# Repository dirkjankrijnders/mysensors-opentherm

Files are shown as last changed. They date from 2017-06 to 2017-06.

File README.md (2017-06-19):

# mysensors-opentherm
Mysensors opentherm gateway

Effectively a open of http://otgw.tclcode.com, but with external power brick and a MYSX-2.0 connector instead of the RS-232 interface. The PCB is designed to fit in [this](http://www.ebay.com/itm/221899779029) enclosure and connect to https://github.com/dirkjankrijnders/MYS-PMS7003.

3D render of the PCB:

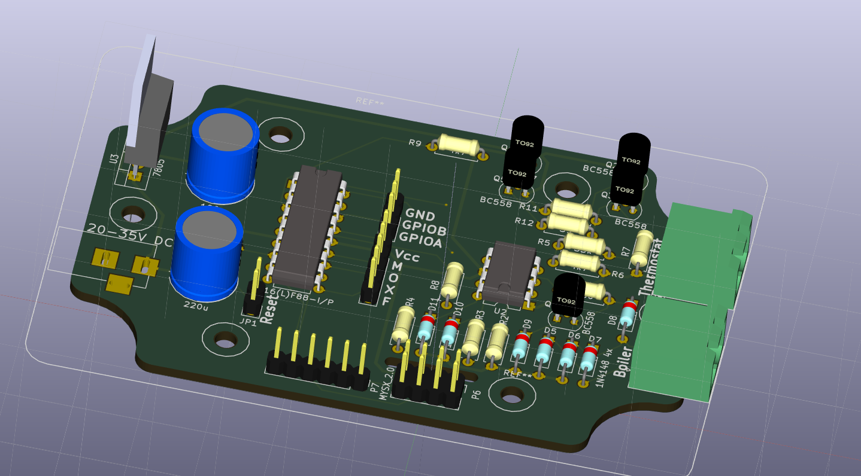
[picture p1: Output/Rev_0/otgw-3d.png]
3D render


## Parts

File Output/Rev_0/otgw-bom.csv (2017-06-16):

Reference | Value | Footprint | Datasheet
P4 | CONN_01X02 | Connectors_Phoenix:PhoenixContact_MSTBA-G_02x5.00mm_Angled
P5 | CONN_01X02 | Connectors_Phoenix:PhoenixContact_MSTBA-G_02x5.00mm_Angled
C1 | 220u | Capacitors_THT:CP_Radial_D10.0mm_P5.00mm_P7.50mm
U3 | 7805 | TO_SOT_Packages_THT:TO-220_Vertical
C2 | 100u | Capacitors_THT:CP_Radial_D10.0mm_P5.00mm_P7.50mm
U1 | PIC16(L)F88-I/P | Housings_DIP:DIP-18_W7.62mm
R10 | 15k | Resistors_THT:R_Axial_DIN0207_L6.3mm_D2.5mm_P7.62mm_Horizontal
JP1 | Jumper | Pin_Headers:Pin_Header_Angled_1x02_Pitch2.54mm
P3 | CONN_01X03 | Pin_Headers:Pin_Header_Straight_1x03_Pitch2.54mm
P2 | CONN_01X05 | Pin_Headers:Pin_Header_Straight_1x05_Pitch2.54mm
D5 | 1N4148 | Diodes_THT:D_DO-35_SOD27_P7.62mm_Horizontal
D6 | 1N4148 | Diodes_THT:D_DO-35_SOD27_P7.62mm_Horizontal
D7 | 1N4148 | Diodes_THT:D_DO-35_SOD27_P7.62mm_Horizontal
D8 | 1N4148 | Diodes_THT:D_DO-35_SOD27_P7.62mm_Horizontal
D9 | 4V7 | Diodes_THT:D_DO-35_SOD27_P7.62mm_Horizontal
Q1 | BC558 | TO_SOT_Packages_THT:TO-92_Molded_Narrow
R1 | 330 | Resistors_THT:R_Axial_DIN0207_L6.3mm_D2.5mm_P7.62mm_Horizontal
R3 | 220 | Resistors_THT:R_Axial_DIN0207_L6.3mm_D2.5mm_P7.62mm_Horizontal
R2 | 100 | Resistors_THT:R_Axial_DIN0207_L6.3mm_D2.5mm_P7.62mm_Horizontal
D10 | 15V | Diodes_THT:D_DO-35_SOD27_P7.62mm_Horizontal
D11 | 4V3 | Diodes_THT:D_DO-35_SOD27_P7.62mm_Horizontal
U2 | PC827 | Housings_DIP:DIP-8_W7.62mm
R8 | 1k5 | Resistors_THT:R_Axial_DIN0207_L6.3mm_D2.5mm_P7.62mm_Horizontal
R4 | 330 | Resistors_THT:R_Axial_DIN0207_L6.3mm_D2.5mm_P7.62mm_Horizontal
Q3 | BC558 | TO_SOT_Packages_THT:TO-92_Molded_Narrow
Q2 | BC558 | TO_SOT_Packages_THT:TO-92_Molded_Narrow
R7 | 33k | Resistors_THT:R_Axial_DIN0207_L6.3mm_D2.5mm_P7.62mm_Horizontal
R5 | 33k | Resistors_THT:R_Axial_DIN0207_L6.3mm_D2.5mm_P7.62mm_Horizontal
R6 | 4k7 | Resistors_THT:R_Axial_DIN0207_L6.3mm_D2.5mm_P7.62mm_Horizontal
R11 | 100 | Resistors_THT:R_Axial_DIN0207_L6.3mm_D2.5mm_P7.62mm_Horizontal
R12 | 39 | Resistors_THT:R_Axial_DIN0207_L6.3mm_D2.5mm_P7.62mm_Horizontal
Q5 | BC558 | TO_SOT_Packages_THT:TO-92_Molded_Narrow
Q4 | BC547 | TO_SOT_Packages_THT:TO-92_Molded_Narrow
R9 | 4k7 | Resistors_THT:R_Axial_DIN0207_L6.3mm_D2.5mm_P7.62mm_Horizontal
P7 | CONN_01X06 | Pin_Headers:Pin_Header_Straight_1x06_Pitch2.54mm
P6 | MYSX_2.0 | mysensors_connectors:MYSX_2.0
CON1 | BARREL_JACK | Connectors:BARREL_JACK

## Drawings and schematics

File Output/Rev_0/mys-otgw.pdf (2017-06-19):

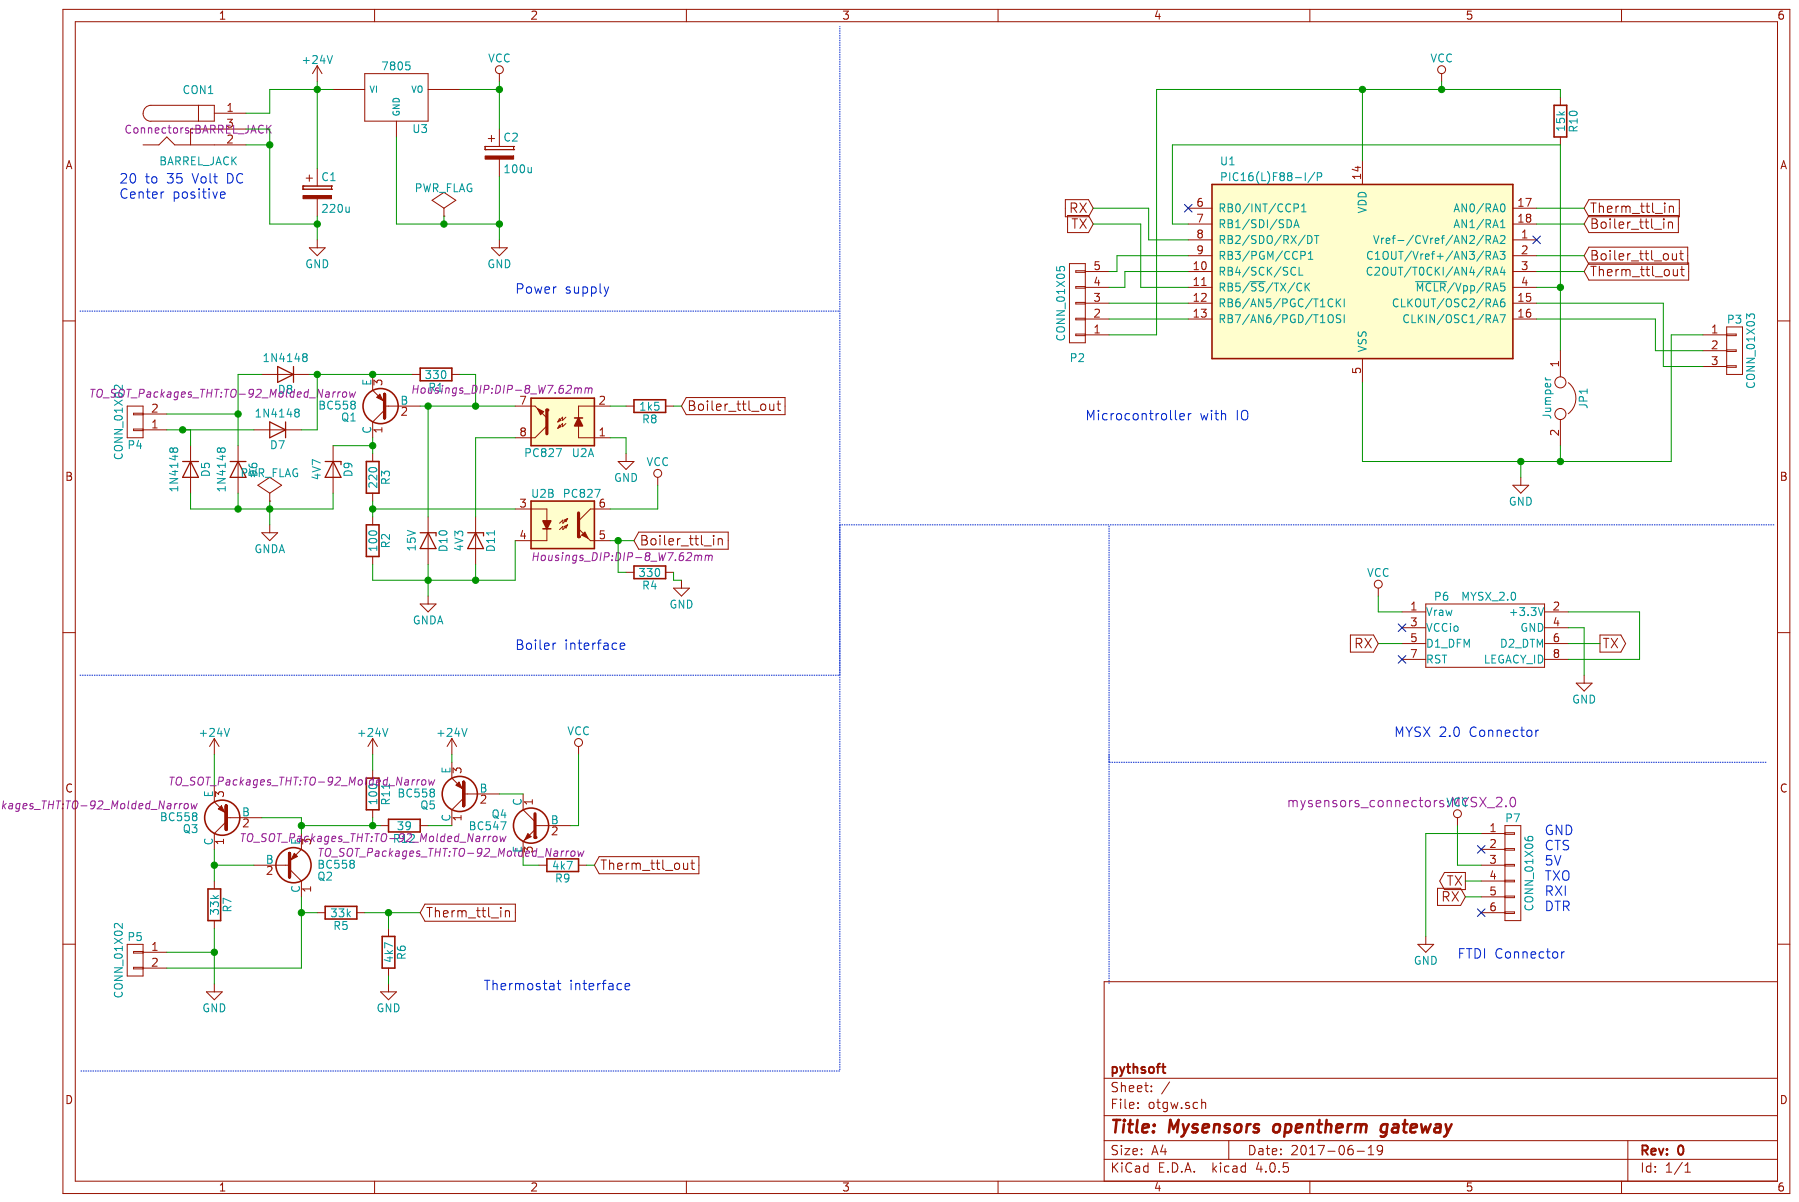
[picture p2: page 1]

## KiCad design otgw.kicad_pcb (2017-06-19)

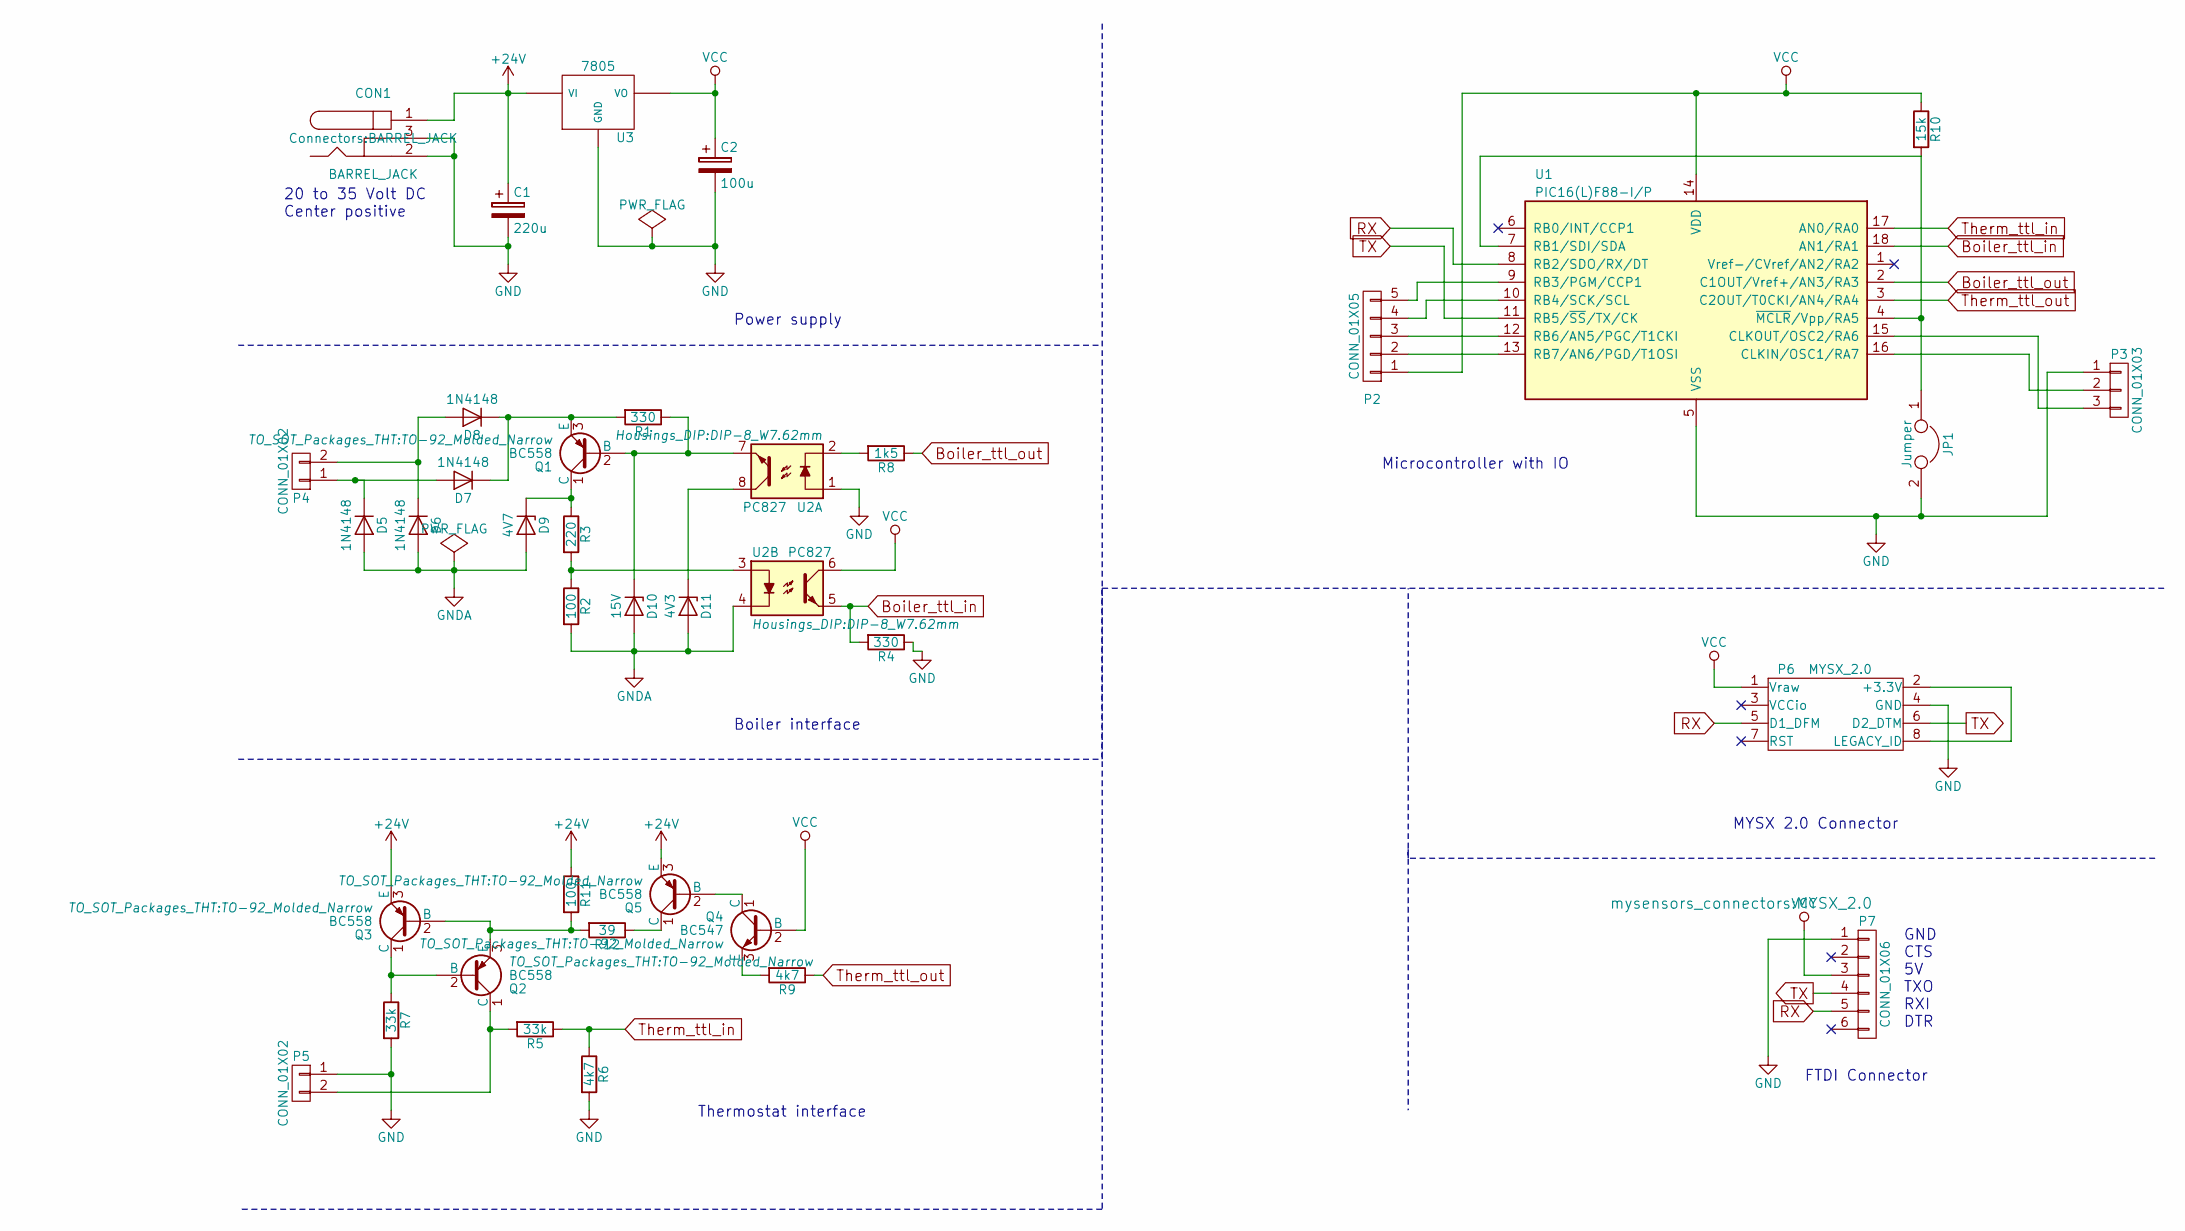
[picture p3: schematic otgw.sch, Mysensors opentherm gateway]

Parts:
C1: 220u; CP_Radial_D10.0mm_P5.00mm_P7.50mm
C2: 100u; CP_Radial_D10.0mm_P5.00mm_P7.50mm
CON1: BARREL_JACK
D5, D6, D7, D8: 1N4148; D_DO-35_SOD27_P7.62mm_Horizontal
D9: 4V7; D_DO-35_SOD27_P7.62mm_Horizontal
D10: 15V; D_DO-35_SOD27_P7.62mm_Horizontal
D11: 4V3; D_DO-35_SOD27_P7.62mm_Horizontal
JP1: Jumper; Pin_Header_Angled_1x02_Pitch2.54mm
P2: CONN_01X05; Pin_Header_Straight_1x05_Pitch2.54mm
P3: CONN_01X03; Pin_Header_Straight_1x03_Pitch2.54mm
P4, P5: CONN_01X02; PhoenixContact_MSTBA-G_02x5.00mm_Angled
P6: MYSX_2.0
P7: CONN_01X06; Pin_Header_Straight_1x06_Pitch2.54mm
Q1, Q2, Q3, Q5: BC558; TO-92_Molded_Narrow
Q4: BC547; TO-92_Molded_Narrow
R1, R4: 330; R_Axial_DIN0207_L6.3mm_D2.5mm_P7.62mm_Horizontal
R2, R11: 100; R_Axial_DIN0207_L6.3mm_D2.5mm_P7.62mm_Horizontal
R3: 220; R_Axial_DIN0207_L6.3mm_D2.5mm_P7.62mm_Horizontal
R5, R7: 33k; R_Axial_DIN0207_L6.3mm_D2.5mm_P7.62mm_Horizontal
R6, R9: 4k7; R_Axial_DIN0207_L6.3mm_D2.5mm_P7.62mm_Horizontal
R8: 1k5; R_Axial_DIN0207_L6.3mm_D2.5mm_P7.62mm_Horizontal
R10: 15k; R_Axial_DIN0207_L6.3mm_D2.5mm_P7.62mm_Horizontal
R12: 39; R_Axial_DIN0207_L6.3mm_D2.5mm_P7.62mm_Horizontal
U1: PIC16(L)F88-I/P; DIP-18_W7.62mm
U2: PC827; DIP-8_W7.62mm
U3: 7805; TO-220_Vertical

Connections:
+24V: C1.1, CON1.1, Q3.3 (E), Q5.3 (E), R11.1, U3.1 (VI)
Boiler_ttl_in: R4.2, U1.18 (AN1/RA1), U2.5
Boiler_ttl_out: R8.1, U1.2 (C1OUT/Vref+/AN3/RA3)
GND: C1.2, C2.2, CON1.2, CON1.3, JP1.2, P3.1, P5.1, P6.4 (GND), P7.1, R4.1, R6.2, R7.2, U1.5 (VSS), U2.1, U3.2 (GND)
GNDA: D5.2 (A), D6.2 (A), D9.2 (A), D10.2 (A), D11.2 (A), R2.2, U2.4
unnamed: D5.1 (K), D7.2 (A), P4.1
unnamed: D6.1 (K), D8.2 (A), P4.2
unnamed: D7.1 (K), D8.1 (K), Q1.3 (E), R1.2
unnamed: D9.1 (K), Q1.1 (C), R3.1
unnamed: D10.1 (K), Q1.2 (B), R1.1, U2.7
unnamed: D11.1 (K), U2.8
unnamed: JP1.1, R10.2, U1.4 (~MCLR~/Vpp/RA5), U1.7 (RB1/SDI/SDA)
unnamed: P2.2, U1.13 (RB7/AN6/PGD/T1OSI)
unnamed: P2.3, U1.12 (RB6/AN5/PGC/T1CKI)
unnamed: P2.4, U1.10 (RB4/SCK/SCL)
unnamed: P2.5, U1.9 (RB3/PGM/CCP1)
unnamed: P3.2, U1.16 (CLKIN/OSC1/RA7)
unnamed: P3.3, U1.15 (CLKOUT/OSC2/RA6)
unnamed: P5.2, Q2.1 (C), R5.2
unnamed: P6.2 (+3.3V), P6.8 (LEGACY_ID)
unnamed: Q2.2 (B), Q3.1 (C), R7.1
unnamed: Q2.3 (E), Q3.2 (B), R11.2, R12.2
unnamed: Q4.1 (C), Q5.2 (B)
unnamed: Q4.3 (E), R9.2
unnamed: Q5.1 (C), R12.1
unnamed: R2.1, R3.2, U2.3
unnamed: R8.2, U2.2
RX: P6.5 (D1_DFM), P7.5, U1.8 (RB2/SDO/RX/DT)
TX: P6.6 (D2_DTM), P7.4, U1.11 (RB5/~SS~/TX/CK)
Therm_ttl_in: R5.1, R6.1, U1.17 (AN0/RA0)
Therm_ttl_out: R9.1, U1.3 (C2OUT/T0CKI/AN4/RA4)
VCC: C2.1, P2.1, P6.1 (Vraw), P7.3, Q4.2 (B), R10.1, U1.14 (VDD), U2.6, U3.3 (VO)

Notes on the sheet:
GND CTS 5V TXO RXI DTR
MYSX 2.0 Connector
FTDI Connector
Thermostat interface
Boiler interface
Power supply
20 to 35 Volt DC Center positive
Microcontroller with IO

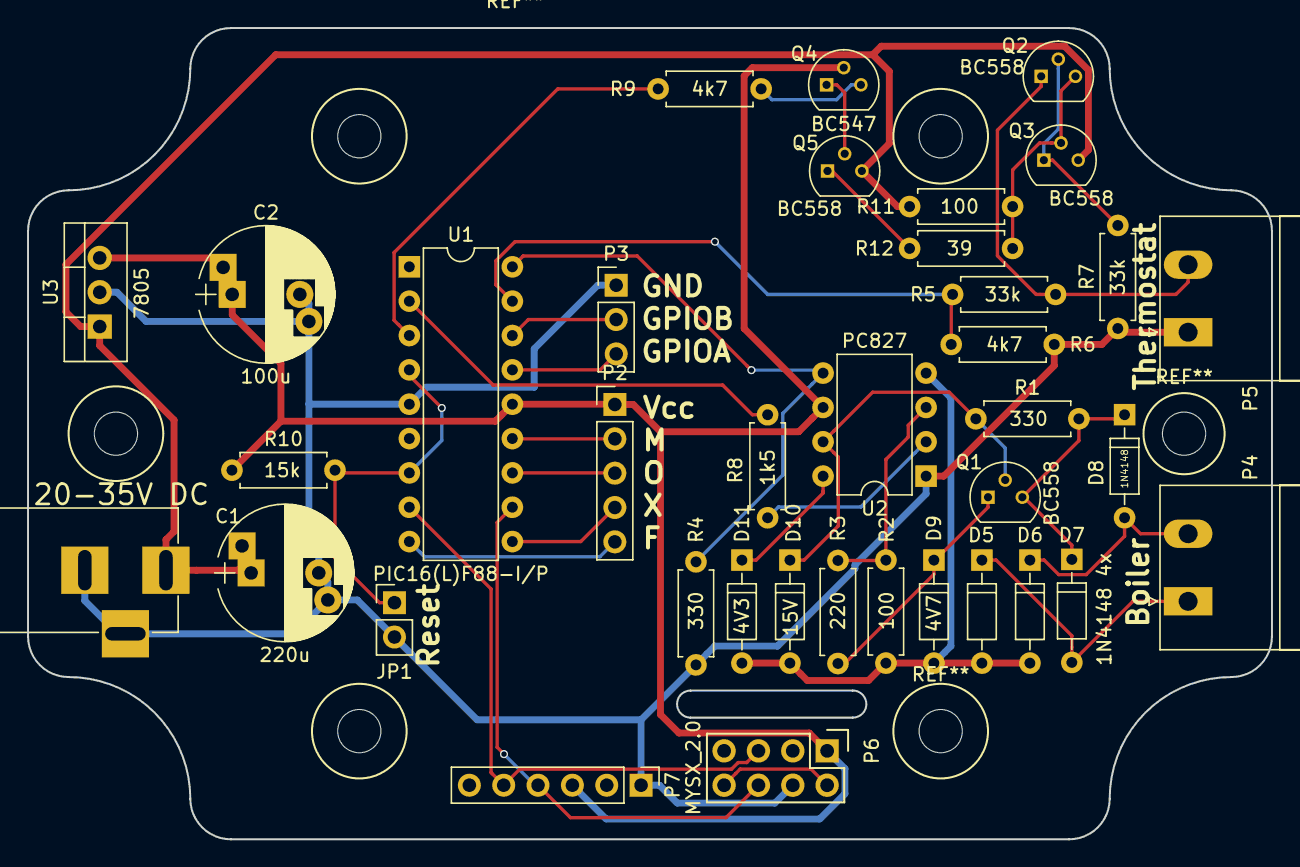
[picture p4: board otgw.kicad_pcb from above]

Board: 2 copper layers, 92.0 x 60.0 mm, 37 parts (0 on the bottom side), 32 nets.

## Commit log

2017-06-16 Added PCB design files
    [otgw.kicad_pcb, otgw.sch]
2017-06-16 Added standard BOM from KiCad
    [otgw-bom.csv]
2017-06-16 Added a slot for the MYSX cable to go to the other side of the board
    [otgw.kicad_pcb]
2017-06-16 Adjusted GND plane to recent changes
    [otgw.kicad_pcb]
2017-06-19 Added production outputs
    [otgw-bom.csv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]
2017-06-19 Fixed the silk screen
    [otgw-B.Cu.gbl, otgw-B.Mask.gbs, otgw-B.SilkS.gbo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]
2017-06-19 Annotations on the schematic and some small Silkscreen additions
    [otgw.kicad_pcb, otgw.sch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]
2017-06-19 Centered a mounting hole
    [otgw.kicad_pcb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]
